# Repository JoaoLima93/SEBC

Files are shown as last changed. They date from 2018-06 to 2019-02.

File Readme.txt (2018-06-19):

** Low Cost Embedded System for Dynamic Rate Simulation: Tarifa Branca **

This work aims to present a proposal for a system design compatible with electronic meters approved by INMETRO, which simulates the billing of White Rate customers, to assist them in the decision making of their tariff modality, since the implementation of the new model may cause doubts about its operation. In this way a low-cost electronic module will be proposed, applying the embedded system development methods for building the solution through the open source development platforms NodeMCU, KiCad, Lua Language, MySql and Android Studio.

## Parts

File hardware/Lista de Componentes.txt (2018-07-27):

---------------------------- Lista de Componente -------------------------------
- NodeMCU
--> Alimentação
1 Barrel Jack
1 Fonte de Saída de 5v
1 Zener
1 L7805
2 capacitores eletrolitico de 10 uF

--> Sensor de Corrente
- 4 Resistor 10K 1/4W
- 2 Capacitor 100µF 16V
- 2 Conector Jack P2 Audio 3.5mm-

-->Sensor de Tensão
- 2 Conector Borne
- 2 4n25 octoacoplador
- 2 resistor 220k
- 2 Resistor 10k
- 2 capacitor de 100 uF

--> Outras coisas
~* Multiplexador Analogico HEF4051B
~* Modulo Micro Sd
https://produto.mercadolivre.com.br/MLB-708923667-modulo-leitor-carto-micro-sd-card-leituraescrita-arduino-_JM

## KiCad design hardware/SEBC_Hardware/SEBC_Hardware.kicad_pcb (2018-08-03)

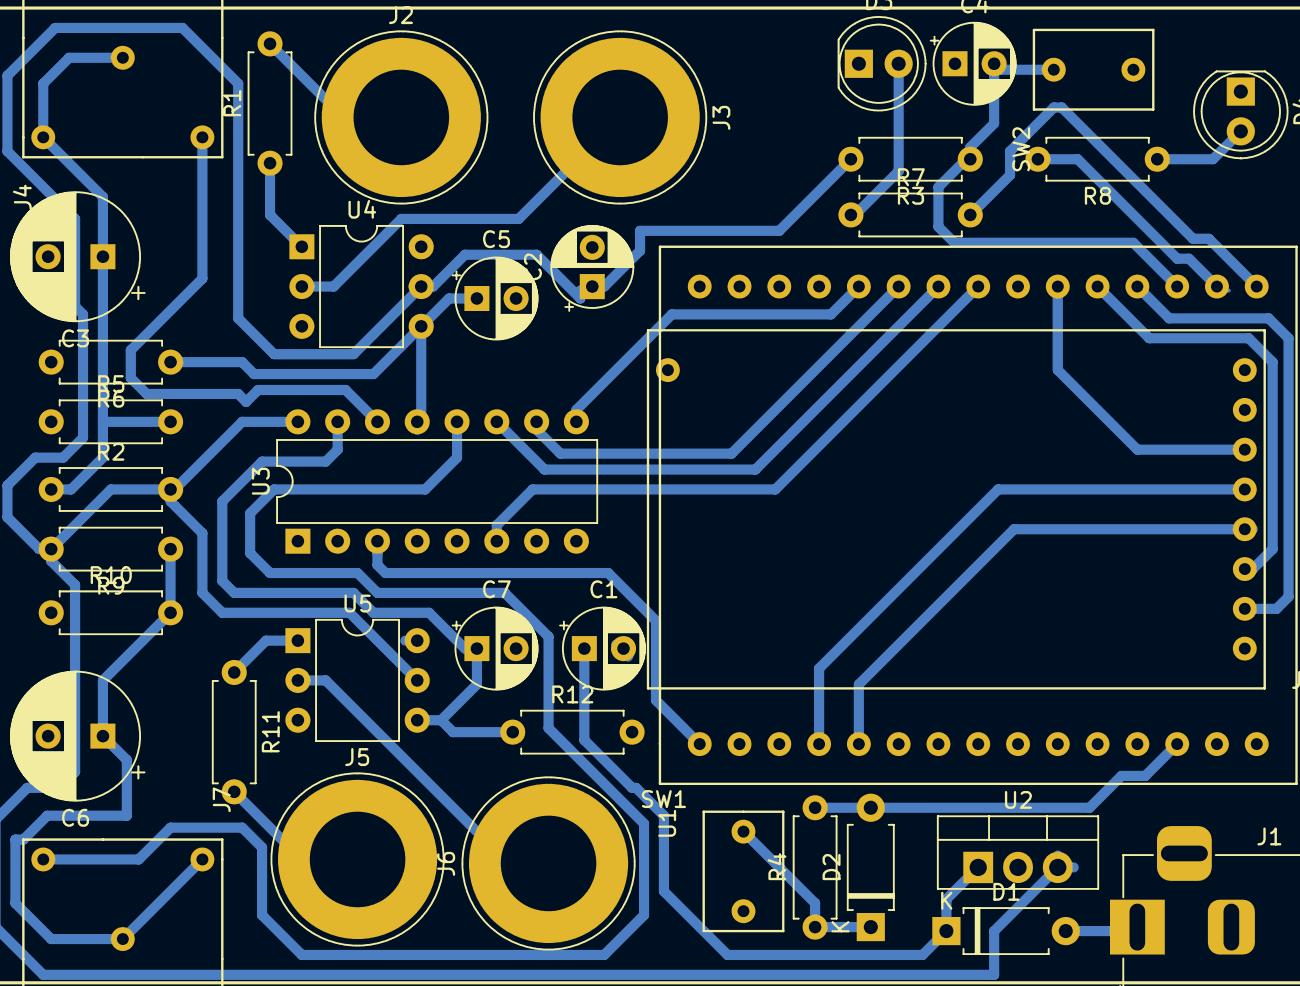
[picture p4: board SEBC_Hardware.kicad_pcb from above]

Board: 2 copper layers, 38 parts (0 on the bottom side), 33 nets.

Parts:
C1, C2, C5, C7: 10uF; CP_Radial_D5.0mm_P2.50mm
C3, C6: 100 uF; CP_Radial_D8.0mm_P3.50mm
C4: 100 n; CP_Radial_D5.0mm_P2.50mm
D1: D_Zener_ALT; D_A-405_P7.62mm_Horizontal
D2: DIODE; D_A-405_P7.62mm_Horizontal
D3, D4: LED_ALT; LED_D5.0mm
J1: Barrel_Jack_Switch; BarrelJack_Horizontal
J2, J3, J5, J6: Conn_01x01_Female; Banana_Jack_1Pin
J4, J7: AudioJack2_Ground_Switch; JACKAUDIO_P2
J8: Micro_SD_Card; microSD
R1, R11: 220k; R_Axial_DIN0207_L6.3mm_D2.5mm_P7.62mm_Horizontal
R2, R4, R5, R9, R10: 10 k; R_Axial_DIN0207_L6.3mm_D2.5mm_P7.62mm_Horizontal
R3: 1k; R_Axial_DIN0207_L6.3mm_D2.5mm_P7.62mm_Horizontal
R6, R12: 10k; R_Axial_DIN0207_L6.3mm_D2.5mm_P7.62mm_Horizontal
R7, R8: 1 k; R_Axial_DIN0207_L6.3mm_D2.5mm_P7.62mm_Horizontal
SW1, SW2: SW_Push; push_button
U1: NodeMCU1.0(ESP-12E); nodmcu
U2: L7805; TO-220-3_Vertical
U3: 4051; DIP-16_W7.62mm
U4, U5: 4N25; DIP-6_W7.62mm

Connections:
+3V3: J8.6, U1.25
+5V: C2.1, R2.2, R3.2, R9.2, U1.15, U2.3, U3.16, U4.5, U5.5
/A0: U1.22, U3.11
/A1: U1.21, U3.10
/A2: U1.20, U3.9
/Boot: C4.2, R3.1, SW2.1, U1.28
/INN_E: U1.23, U3.6
/LED_01: R7.2, U1.30
/LED_02: R8.2, U1.29
/Reset: D2.2, R4.2, U1.13
/SD1: J8.2, U1.27
/SD2: J8.3, U1.26
/SD3: J8.4, U1.5
/SD4: J8.5, U1.4
/SENSOR_C_A: J4.S, U3.14
/SENSOR_C_B: J7.S, U3.12
/SENSOR_T_A: C5.1, R6.1, U3.13, U4.4
/SENSOR_T_B: C7.1, R12.1, U3.15, U5.4
/S_MUX: U1.1, U3.3
GND: C1.2, C2.2, C3.2, C4.1, C5.2, C6.2, C7.2, D3.1, D4.1, J1.2, J1.3, R5.1, R6.2, R10.1, R12.2, SW1.2, SW2.2, U1.14, U2.2, U3.7, U3.8
unnamed: C1.1, D1.1, U2.1
unnamed: C3.1, J4.T, J4.TN, R2.1, R5.2
unnamed: C6.1, J7.T, J7.TN, R9.1, R10.2
unnamed: D1.2, J1.1
unnamed: D2.1, R4.1, SW1.1
unnamed: D3.2, R7.1
unnamed: D4.2, R8.1
unnamed: J2.1, R1.2
unnamed: J3.1, U4.2
unnamed: J5.1, R11.2
unnamed: J6.1, U5.2
unnamed: R1.1, U4.1
unnamed: R11.1, U5.1

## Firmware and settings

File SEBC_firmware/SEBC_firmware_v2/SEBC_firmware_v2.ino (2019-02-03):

/* 
-------------------------------------------------------------------------------------
Sistema Embarcado para Avaliação de Viabilidade 
de Tarifas Dinâmicas: Tarifa Branca
-------------------------------------------------------------------------------------
Desenvolvimento:
Joao Pedro de Lima                               lima.joaopedro@live.com
-------------------------------------------------------------------------------------
As bibliotecas biblioteca foram utilizada pelos seguintes github:
<ESP8266WiFi.h> https://github.com/esp8266/Arduino/tree/master/libraries/ESP8266WiFi
<NTPClient.h>   https://github.com/arduino-libraries/NTPClient
<WiFiUdp.h>     https://github.com/esp8266/Arduino/tree/master/libraries/ESP8266WiFi  
------------------------------------------------------------------------------------- 
*/
#include <ESP8266WiFi.h>
#include <NTPClient.h>
#include <WiFiUdp.h> 
#include <SPI.h>
#include <SD.h>
#include "EmonLib.h"         

EnergyMonitor Monitor_A;
EnergyMonitor Monitor_B;
EnergyMonitor Monitor_C;
File leituraSD;
File leituraNaoIntegradaSD;

const char* ssid         = "Net Lima";        // Nome do seu WIFI (SSID)
const char* password     = "#anaJOAO2009#";   // Senha do WIFI
int    id_cliente;

const int Led_Conexao    =  16;               // Led para verificar conex�o WiFi
const int Led_Energia    =   5;               // Led para verificar fornecimento de energia

const int Sensores       =  0;                // Porta de Entrada dos Sensores
const int Mux0           =  12;               // Porta de MUX 0
const int Mux1           =  13;               // Porta de MUX 1
const int Mux2           =  14;               // Porta de MUX 2
const int bootloader     =  4;                // Botão de Bootloader

const char* host         = "192.168.0.15";

String num_medidor       = "22051993";        // Numero do equipamento prédefinido
String inStringCL        = "";
const char* inStringRE   = "";
const char* inStringSE   = "";

double Irms_a            = 0;
double V_a               = 0;
double fp_a              = 0;
double leitura_a         = 0;
double Irms_b            = 0;
double V_b               = 0;
double fp_b              = 0;
double leitura_b         = 0;
double Irms_c            = 0;
double V_c               = 0;
double fp_c              = 0;
double leitura_c         = 0;

int encontraBarra        = 0;                      // Variavel para quebrar a informação vinda da API

// Configurando Servidor NTP Brasil
WiFiUDP ntpUDP;
NTPClient timeClient(ntpUDP, "a.st1.ntp.br", -3 * 3600, 60000);

void setup() {
  // Configuracao de Sensores
  Monitor_A.current(Sensores,30);
  Monitor_A.voltage(Sensores,71.1,1.7);

  Monitor_B.current(Sensores,30);
  Monitor_B.voltage(Sensores,71.1,1.7);

  Monitor_C.current(Sensores,30);
  Monitor_C.voltage(Sensores,71.1,1.7);
  
  pinMode(Mux0, OUTPUT);
  pinMode(Mux1, OUTPUT);
  pinMode(Mux2, OUTPUT);
  
  // Configuracao da saída Serial    
  Serial.begin(115200);
  delay(10);

  Serial.println();
  Serial.println();
  Serial.print("Connecting to ");
  Serial.println(ssid);

  // Configuracao da conexão WiFi    
  WiFi.mode(WIFI_STA);
  WiFi.begin(ssid, password);
  
  while (WiFi.status() != WL_CONNECTED) {
    delay(500);
    Serial.print(".");
  }

  Serial.println("");
  Serial.println("WiFi connected");  
  Serial.println("IP address: ");
  Serial.println(WiFi.localIP());

  // Configuracao NTP   
  timeClient.begin();

  // Configurando Botão de Loader
  pinMode(bootloader, INPUT);

  // Configurando Cliente
  id_cliente =0;
  
}

void loop() {

   digitalWrite(Led_Energia, HIGH);
    
   timeClient.update();                                 
    
   //   Sensor de Potencia A
   digitalWrite(Mux0, LOW);  
   digitalWrite(Mux1, LOW);
   Monitor_A.calcVI(20,2000);   

   Irms_a = Monitor_A.Irms;
   V_a    = Monitor_A.Vrms;   
   fp_a   = Monitor_A.powerFactor;
   leitura_a = Monitor_A.realPower;

   delay(100);
   
   //   Sensor de Potencia B
   digitalWrite(Mux0, LOW);
   digitalWrite(Mux1, HIGH);  
   Monitor_B.calcVI(20,2000);   

   Irms_b = Monitor_B.Irms;
   V_b    = Monitor_B.Vrms;   
   fp_b   = Monitor_B.powerFactor;
   leitura_b = Monitor_B.realPower;
 
   delay(100);
   
   //   Sensor de Potencia C
   digitalWrite(Mux0, HIGH);
   digitalWrite(Mux1, LOW); 
   Monitor_C.calcVI(20,2000);   

   Irms_c = Monitor_C.Irms;
   V_c    = Monitor_C.Vrms;   
   fp_c   = Monitor_C.powerFactor;
   leitura_c = Monitor_C.realPower;
   
   delay(100);

  // Valida conexao com a Internet
  WiFiClient client;
  const int httpPort = 80;
  if (!client.connect(host, httpPort)) {
    digitalWrite(Led_Conexao, LOW);     
    return;
  }
  digitalWrite(Led_Conexao, HIGH);

  //Botão de bootloader
   byte carregaCliente = digitalRead(bootloader); 
   if((inStringCL == "") or (carregaCliente == true)) {
        Serial.print("Atualizando Cliente ..... ");
        String url1 = "/sebc/IntegraSE/vinculaCliente.php?";
               url1 += "num_medidor=";
               url1 += num_medidor;
        client.print(String("GET ") + url1 + " HTTP/1.1\r\n" +
                     "Host: " + host + "\r\n" + 
                     "Connection: close\r\n\r\n");
        unsigned long timeout2 = millis();
        while (client.available() == 0) {
          if (millis() - timeout2 > 5000) {
            Serial.println(">>> Client Timeout !");
            client.stop();
            return;
          }
        } 
        delay(1000);
        char status[32] = {0};
        client.readBytesUntil('\r', status, sizeof(status));
      if (strcmp(status, "HTTP/1.1 200 OK") != 0) {
        return;
      } 
      // Skip HTTP headers
      char endOfHeaders[] = "\r\n\r\n";
      if (!client.find(endOfHeaders)) {
        return;
      }
      String caraConct;               // Char para conectenar informação
      while (client.available()) {
        caraConct = client.read();
        if(encontraBarra == 0){
          if(caraConct == "_"){
            encontraBarra = 1;
          }
          inStringCL += caraConct;
        }
        if(encontraBarra == 1){
          if(caraConct == "_"){
            encontraBarra = 2;
          }
          inStringRE += caraConct;
        }
        if(encontraBarra == 2){
          inStringSE += caraConct;
        }        
      }
      ssid         = inStringRE;    
      password     = inStringSE;  
      Serial.println(inStringCL);     
   }
         
  id_cliente = inStringCL.toInt();
  
  // URL de chamada da API
  String url = "/sebc/IntegraSE/incluiConsumo.php?";
         url += "leitura_a=";
         url += leitura_a;
         url += "&leitura_b=";
         url += leitura_b;
         url += "&leitura_c=";
         url += leitura_c;
         url += "&id_cliente=";
         url += id_cliente;
         url += "&hora_consumo=";
         url += timeClient.getFormattedTime();  
         
  //Armazena no SD
  leituraSD = SD.open("leituras.txt",FILE_WRITE);
  if (leituraSD) {
    leituraSD.println(url);
  }
  
  client.print(String("GET ") + url + " HTTP/1.1\r\n" +
               "Host: " + host + "\r\n" + 
               "Connection: close\r\n\r\n");
               
  // Debug via conexao serial   
  unsigned long timeout = millis();
  while (client.available() == 0) {
    if (millis() - timeout > 5000) {
      Serial.println(">>> Client Timeout !");
      client.stop();
      return;
      leituraNaoIntegradaSD = SD.open("leituraNaoIntegrada.txt",FILE_WRITE);
      if (leituraNaoIntegradaSD) {
          leituraNaoIntegradaSD.println(url);
      }
    }
  }

  Serial.print("===============================================");
  Serial.print("Requesting URL: ");
  Serial.println(url);
  Serial.println();
  Serial.print("inStringCL: ");
  Serial.println(inStringCL);
  Serial.print("Id_cliente: ");
  Serial.println(id_cliente);
  Serial.print("Tensão A: ");
  Serial.println(V_a);
  Serial.print("Corrente A: ");
  Serial.println(Irms_a);
  Serial.print("Fator de Potência A: ");
  Serial.println(fp_a);
  Serial.print("Potencia A: ");
  Serial.println(leitura_a);
  Serial.print("Tensão B: ");
  Serial.println(V_b);
  Serial.print("Fator de Potência B: ");
  Serial.println(fp_b);
  Serial.print("Corrente B: ");
  Serial.println(Irms_b);
  Serial.print("Potencia B: ");
  Serial.println(leitura_b);
  Serial.print("Tensão C: ");
  Serial.println(V_c);
  Serial.print("Corrente C: ");
  Serial.println(Irms_c);
  Serial.print("Fator de Potência C: ");
  Serial.println(fp_c);
  Serial.print("Potencia C: ");
  Serial.println(leitura_c);
  Serial.println("Leitura OK");
  delay(1000);
}

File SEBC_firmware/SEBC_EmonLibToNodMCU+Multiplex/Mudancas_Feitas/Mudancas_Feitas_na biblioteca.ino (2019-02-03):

//Arquivo EmonLib.H
void voltage(unsigned int _inPinV, double _VCAL, double _PHASECAL, unsigned int _multiplex);
void current(unsigned int _inPinI, double _ICAL, unsigned int _multiplex);

unsigned int multiplex;

//Arquivo EmonLib.CPP
  ///Adicionado Antes de leituras de Corrente
  if (multiplex ==1){
      digitalWrite(12, LOW);
        digitalWrite(13, LOW); 
    }
    if (multiplex ==2){
      digitalWrite(12, LOW);  
             digitalWrite(13, HIGH);
    }
    if (multiplex ==3){
      digitalWrite(12, HIGH);
      digitalWrite(13, LOW); 
    }
       digitalWrite(14, HIGH);
  
  
  //Adicionado Antes de leituras de Tensão
  if (multiplex ==1){
      digitalWrite(12, LOW);
        digitalWrite(13, LOW); 
    }
    if (multiplex ==2){
      digitalWrite(12, LOW);  
             digitalWrite(13, HIGH);
    }
    if (multiplex ==3){
      digitalWrite(12, HIGH);
      digitalWrite(13, LOW); 
    }
       digitalWrite(14, HIGH);

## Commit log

2018-06-19 :fire: Organização de Arquivos
2018-06-20 :sparkles: Include a button
2018-06-20 :construction: Crate a submit button
2018-06-20 :construction: Submit button
2018-07-24 :computer: Add kicad hardware project
    [SEBC_Hardware.kicad_pcb, SEBC_Hardware.sch]
2018-07-24 :memo: Add Lista de componentes
2018-07-24 :electric_plug: Add sensor
    [SEBC_Hardware.sch]
2018-07-25 :electric_plug: Add mews plugs
    [SEBC_Hardware.sch]
2018-07-27 :memo: Lista de Componente
2018-07-27 :book: ESP8266 Kicad Library
    [SEBC_Hardware.sch]
2018-07-27 :construction: Adicionando MicroSD
    [SEBC_Hardware.sch]
2018-07-27 :memo: Lista de Componente
2018-07-29 :construction_worker: PCB
    [SEBC_Hardware.sch]
2018-07-29 :construction: SEBC PCB
    [SEBC_Hardware.kicad_pcb]
2018-08-03 :zap: ADD `PCB
    [SEBC_Hardware.kicad_pcb]
2018-08-03 :zap: Improving PCB performance
    [SEBC_Hardware.kicad_pcb, SEBC_Hardware.sch]
2018-10-12 :sparkle: Adicionando Leds de comunicação
2018-10-12 :sparkle: Adicionando leitura de multiplas fases
2018-10-12 :sparkle: Adicionando leitura de corrente
2018-11-17 :iphone: Finalização do Login
    [app_bar_painel_admin.xml]
2018-11-29 :sparkle: Add Cadastro de usuario
2019-01-14 :white_check_mark: Incluido Teste de API
2019-01-17 :sparkle: Add APi de consumo
2019-01-18 :sparkle: Add Tipo de Rede
2019-02-03 :bug: Correct bug in real power
    [Mudancas_Feitas_na biblioteca.ino, SEBC_firmware.ino, SEBC_firmware_v1.ino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]
